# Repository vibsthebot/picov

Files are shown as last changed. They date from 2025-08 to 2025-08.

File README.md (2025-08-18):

# picov


A RP2040 powered Pico formfactor devboard using usb-c. It includes a 4x4 2020 neopixel array. The pcb was designed in KiCad.

## Schematic


## PCB


## PCB back art (designed in Figma!)


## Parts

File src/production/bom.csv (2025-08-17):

Designator | Footprint | Quantity | Value | LCSC Part #
C1, C12, C13, C14, C2, C3, C4, C5, C6 | 0402 | 9 | 100nF | C1525
C10, C7 | 0402 | 2 | 10uF | C15525
C11, C8 | 0402 | 2 | 1uF | C52923
C15, C16 | 0402 | 2 | 15pF | C1548
D1 | D_SOD-123 | 1 | 1N5819WS | C191023
J1 | USB_C_Receptacle_G-Switch_GT-USB-7010ASV | 1 | USB_C_Receptacle_USB2.0_16P | C67380
J2, J3 | PinHeader_1x20_P2.54mm_Vertical | 2 | Conn_01x20
J4 | PinHeader_1x03_P2.54mm_Vertical | 1 | Conn_01x03
J5 | SOT-23-6 | 1 | Conn_01x06 | C610271
R1, R2 | 0402 | 2 | 27 | C25100
R3, R4 | 0402 | 2 | 5k1 | C25905
R5, R7 | 0402 | 2 | 1k | C11702
R6 | 0402 | 1 | 10k | C25744
SW1, SW2 | SMD_3x4 | 2 | SW_Push | C455280
U1 | QFN-56-1EP_7x7mm_P0.4mm_EP3.2x3.2mm | 1 | RP2040 | C2040
U10, U11, U12, U13, U14, U15, U16, U17, U18, U19, U2, U5, U6, U7, U8, U9 | LED_WS2812-2020 | 16 | WS2812-2020 | C26159668
U3 | Winbond_USON-8-1EP_3x2mm_P0.5mm_EP0.2x1.6mm | 1 | W25Q16JVUXIQ_TR | C2843335
U4 | SOT-23-6 | 1 | USBLC6-2SC6 | C5180249
Y1 | Crystal_SMD_3225-4Pin_3.2x2.5mm | 1 | ABM8-272-T3 | C9002

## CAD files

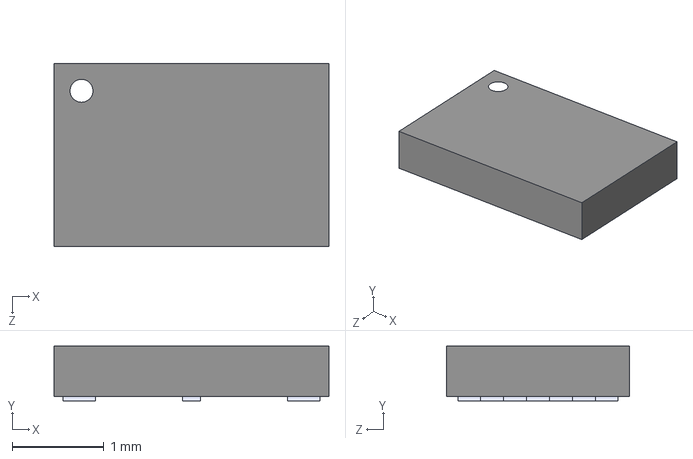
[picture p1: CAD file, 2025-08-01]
src/parts/W25Q16JVUXIQ_TR/W25Q16JVUXIQ_TR.step
3.00 x 0.6 x 2.00 mm

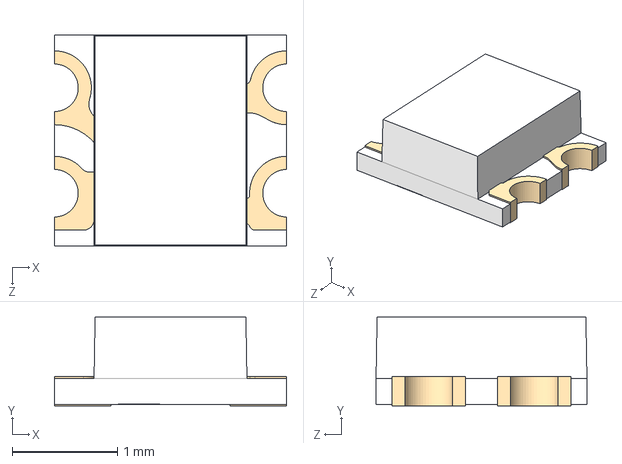
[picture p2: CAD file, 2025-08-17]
src/parts/WS2812-2020/WS2812-2020.step
2.20 x 0.84 x 2.00 mm

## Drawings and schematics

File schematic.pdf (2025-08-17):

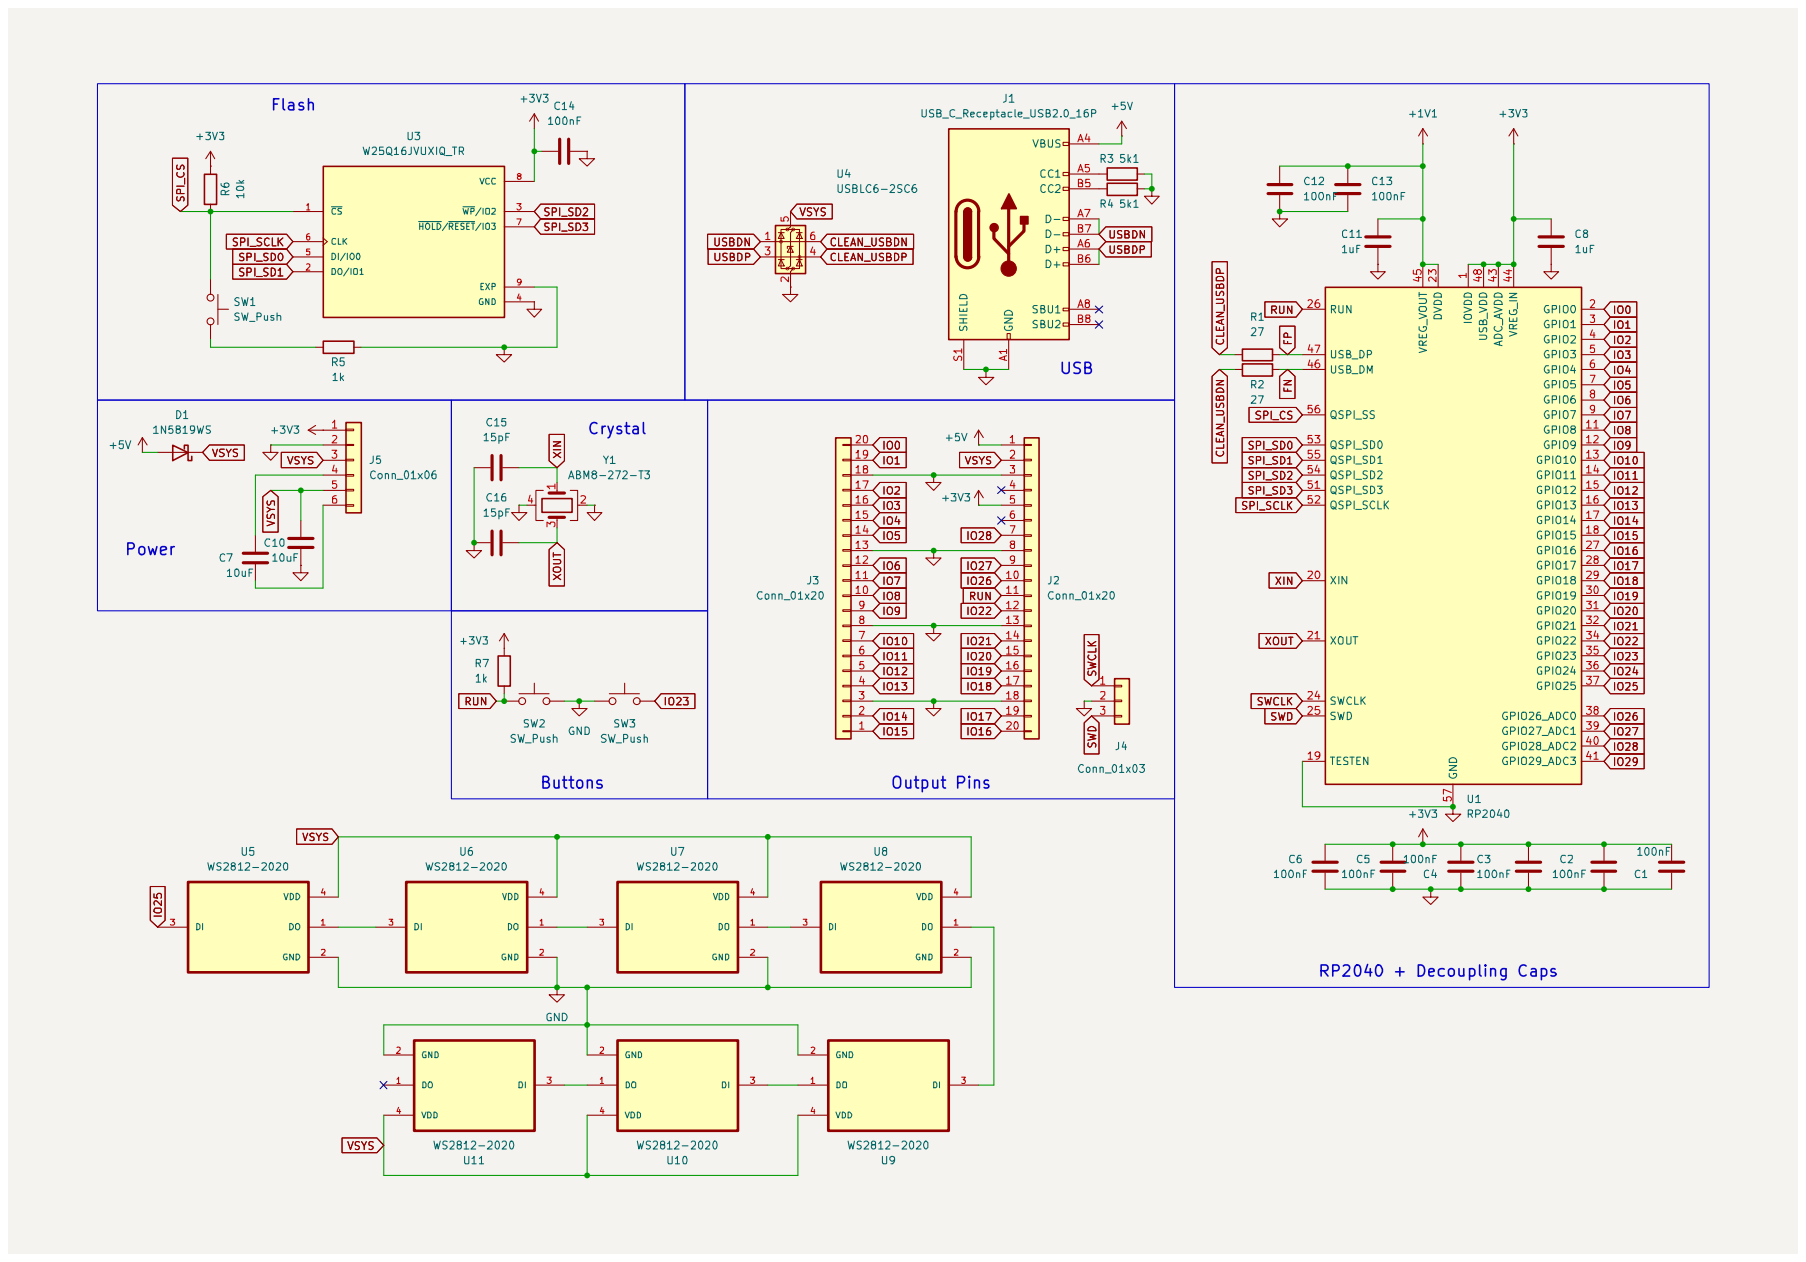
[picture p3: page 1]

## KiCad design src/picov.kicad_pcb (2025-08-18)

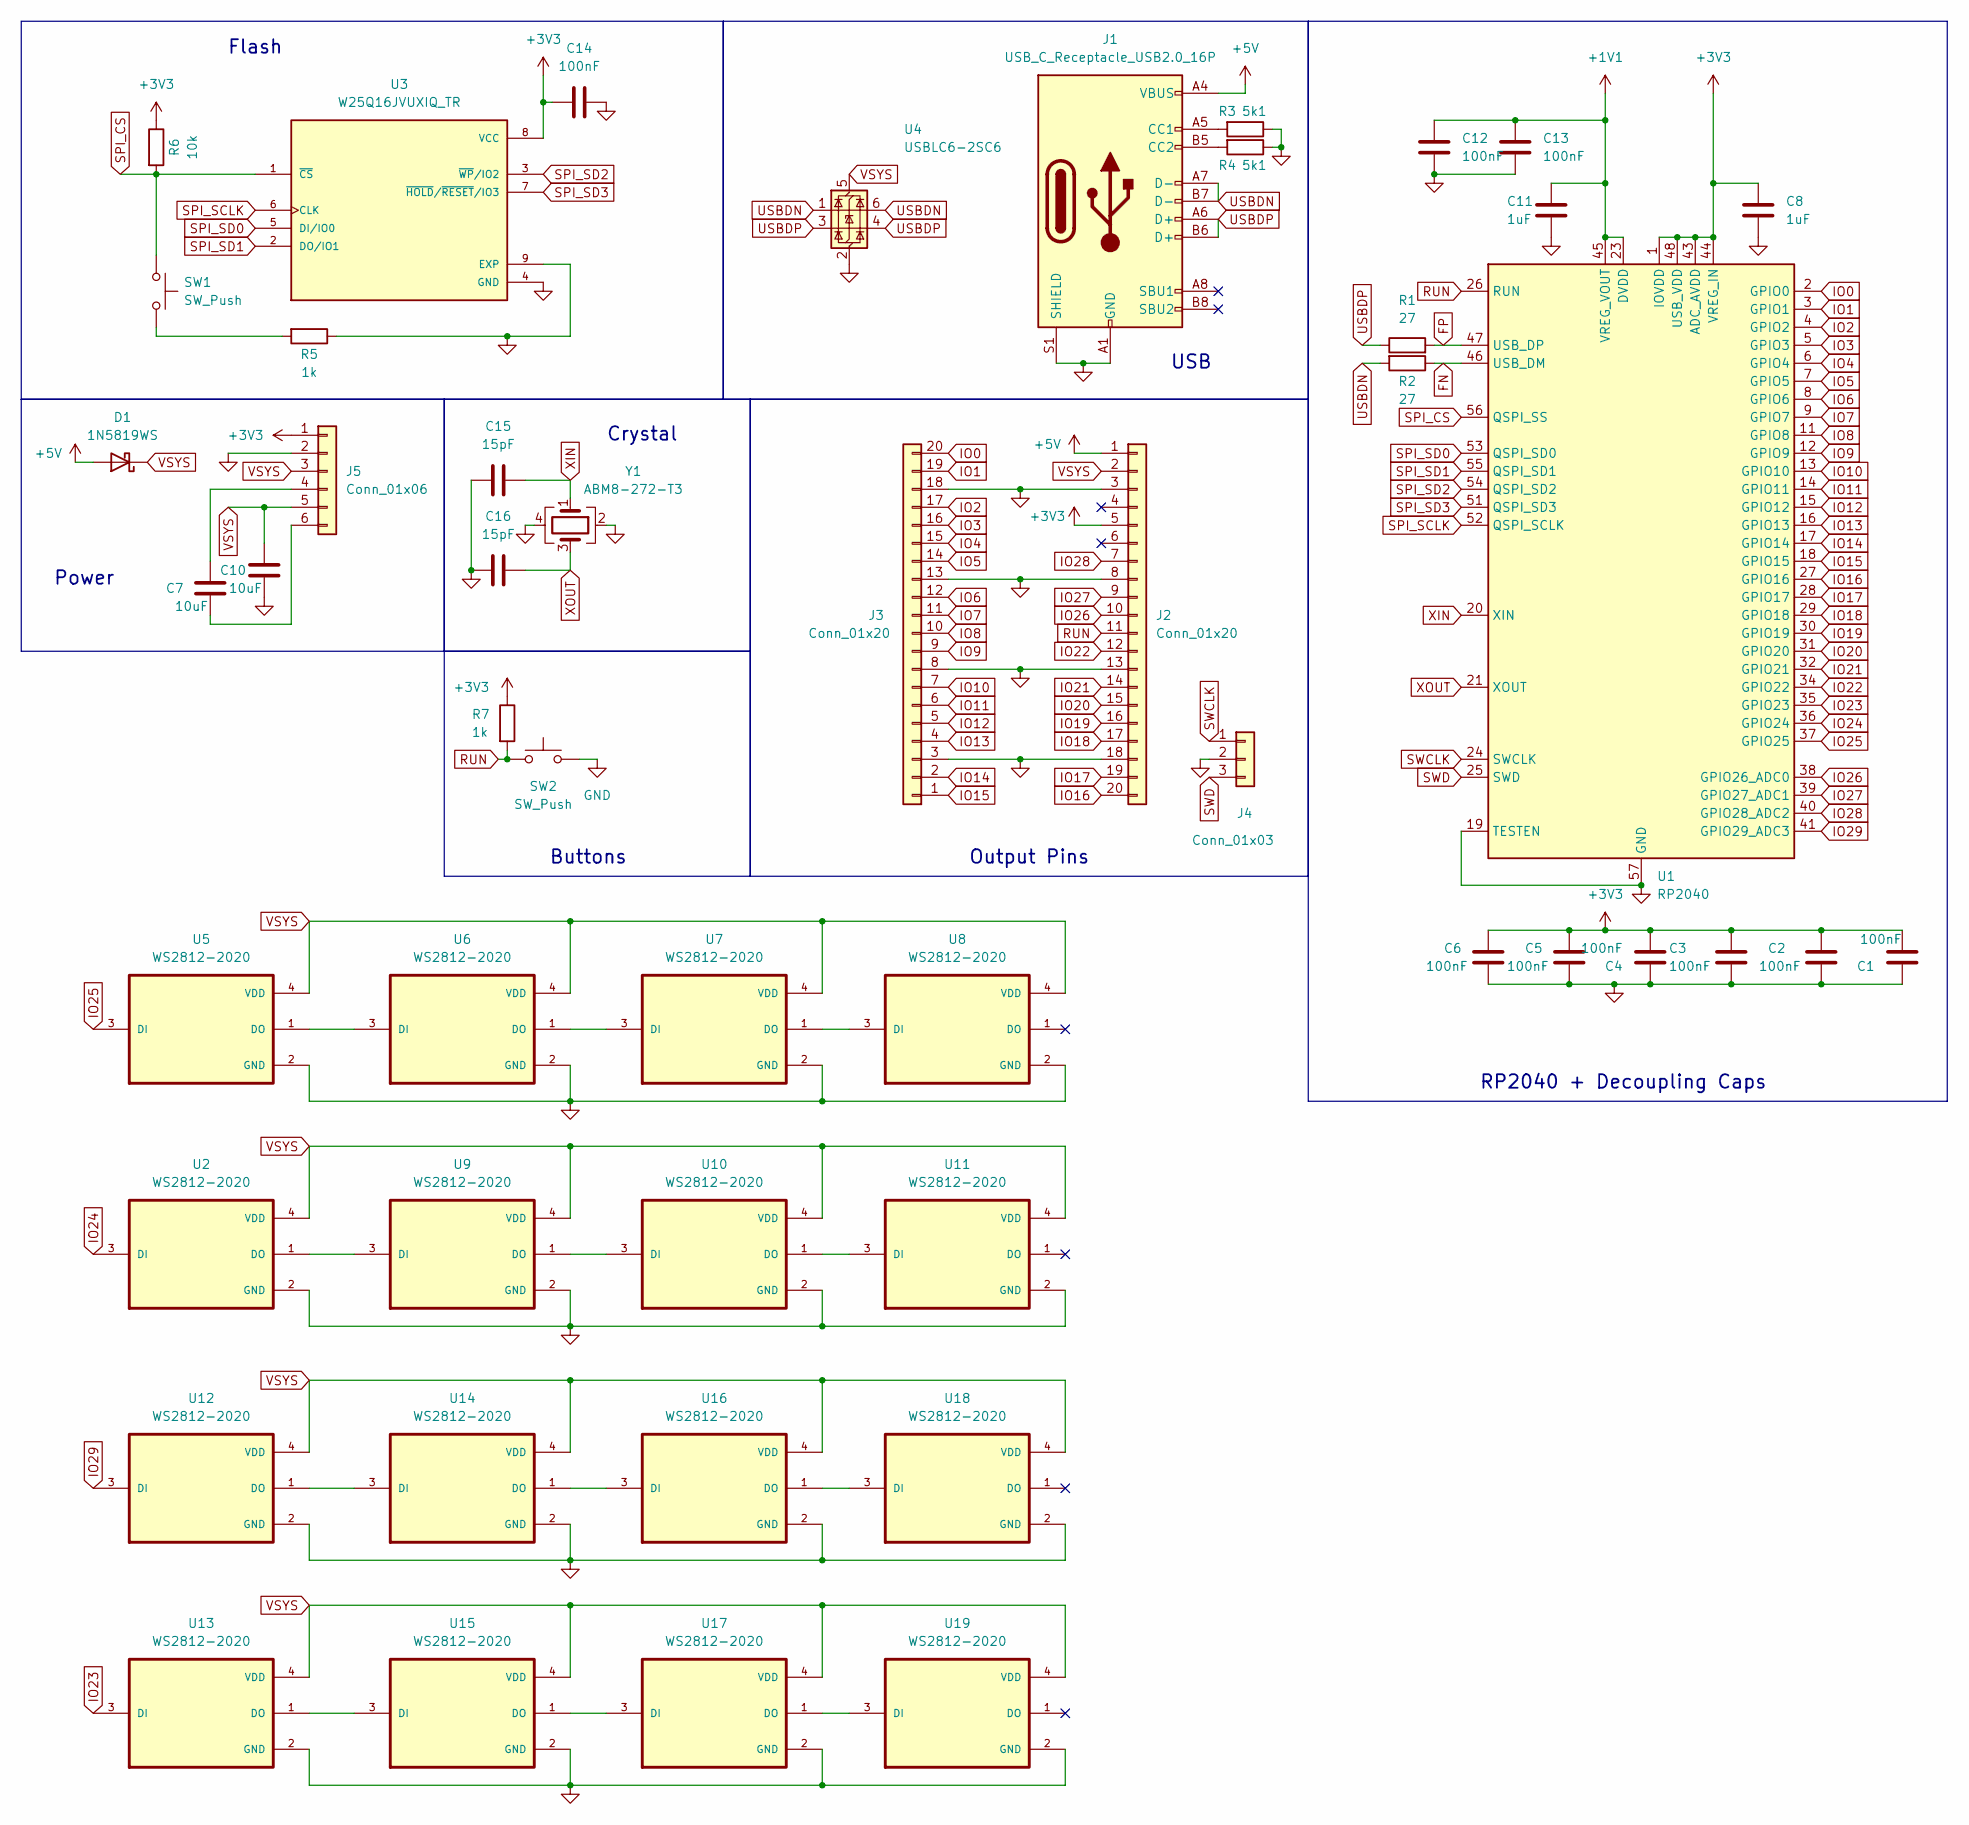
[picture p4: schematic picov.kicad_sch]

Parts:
C1, C2, C3, C4, C5, C6, C12, C13, C14: 100nF; C_0402_1005Metric; LCSC C1525
C7, C10: 10uF; C_0402_1005Metric; LCSC C15525
C8, C11: 1uF; C_0402_1005Metric; LCSC C52923
C15, C16: 15pF; C_0402_1005Metric; LCSC C1548
D1: 1N5819WS; D_SOD-123; LCSC C191023
J1: USB_C_Receptacle_USB2.0_16P; USB_C_Receptacle_G-Switch_GT-USB-7010ASV; LCSC C67380
J2, J3: Conn_01x20; PinHeader_1x20_P2.54mm_Vertical
J4: Conn_01x03; PinHeader_1x03_P2.54mm_Vertical
J5: Conn_01x06; SOT-23-6; LCSC C610271
R1, R2: 27; R_0402_1005Metric; LCSC C25100
R3, R4: 5k1; R_0402_1005Metric; LCSC C25905
R5, R7: 1k; R_0402_1005Metric; LCSC C11702
R6: 10k; R_0402_1005Metric; LCSC C25744
SW1, SW2: SW_Push; SMD_3x4; LCSC C455280
U1: RP2040; QFN-56-1EP_7x7mm_P0.4mm_EP3.2x3.2mm; LCSC C2040
U2, U5, U6, U7, U8, U9, U10, U11, U12, U13, U14, U15, U16, U17, U18, U19: WS2812-2020; LED_WS2812-2020; PARTREV V1.3; LCSC C26159668
U3: W25Q16JVUXIQ_TR; Winbond_USON-8-1EP_3x2mm_P0.5mm_EP0.2x1.6mm; PARTREV H; LCSC C2843335
U4: USBLC6-2SC6; SOT-23-6; LCSC C5180249
Y1: ABM8-272-T3; Crystal_SMD_3225-4Pin_3.2x2.5mm; LCSC C9002

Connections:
+1V1: C11.1, C12.1, C13.1, U1.23 (DVDD), U1.45 (VREG_VOUT), U1.50 (DVDD)
+3V3: C1.2, C2.2, C3.2, C4.2, C5.2, C6.2, C8.1, C14.1, J2.5, J5.1, R6.1, R7.1, U1.1 (IOVDD), U1.10 (IOVDD), U1.22 (IOVDD), U1.33 (IOVDD), U1.42 (IOVDD), U1.43 (ADC_AVDD), U1.44 (VREG_IN), U1.48 (USB_VDD), U1.49 (IOVDD), U3.8 (VCC)
+5V: D1.2 (A), J1.A4 (VBUS), J1.A9 (VBUS), J1.B4 (VBUS), J1.B9 (VBUS), J2.1
FN: R2.1, U1.46 (USB_DM)
FP: R1.2, U1.47 (USB_DP)
GND: C1.1, C2.1, C3.1, C4.1, C5.1, C6.1, C8.2, C10.2, C11.2, C12.2, C13.2, C14.2, C15.1, C16.1, J1.A1 (GND), J1.A12 (GND), J1.B1 (GND), J1.B12 (GND), J1.S1 (SHIELD), J2.3, J2.8, J2.13, J2.18, J3.3, J3.8, J3.13, J3.18, J4.2, J5.2, R3.1, R4.1, R5.1, SW2.2, U1.19 (TESTEN), U1.57 (GND), U2.2 (GND), U3.4 (GND), U3.9 (EXP), U4.2 (GND), U5.2 (GND), U6.2 (GND), U7.2 (GND), U8.2 (GND), U9.2 (GND), U10.2 (GND), U11.2 (GND), U12.2 (GND), U13.2 (GND), U14.2 (GND), U15.2 (GND), U16.2 (GND), U17.2 (GND), U18.2 (GND), U19.2 (GND), Y1.2, Y1.4
IO0: J3.20, U1.2 (GPIO0)
IO1: J3.19, U1.3 (GPIO1)
IO2: J3.17, U1.4 (GPIO2)
IO3: J3.16, U1.5 (GPIO3)
IO4: J3.15, U1.6 (GPIO4)
IO5: J3.14, U1.7 (GPIO5)
IO6: J3.12, U1.8 (GPIO6)
IO7: J3.11, U1.9 (GPIO7)
IO8: J3.10, U1.11 (GPIO8)
IO9: J3.9, U1.12 (GPIO9)
IO10: J3.7, U1.13 (GPIO10)
IO11: J3.6, U1.14 (GPIO11)
IO12: J3.5, U1.15 (GPIO12)
IO13: J3.4, U1.16 (GPIO13)
IO14: J3.2, U1.17 (GPIO14)
IO15: J3.1, U1.18 (GPIO15)
IO16: J2.20, U1.27 (GPIO16)
IO17: J2.19, U1.28 (GPIO17)
IO18: J2.17, U1.29 (GPIO18)
IO19: J2.16, U1.30 (GPIO19)
IO20: J2.15, U1.31 (GPIO20)
IO21: J2.14, U1.32 (GPIO21)
IO22: J2.12, U1.34 (GPIO22)
IO23: U1.35 (GPIO23), U13.3 (DI)
IO24: U1.36 (GPIO24), U2.3 (DI)
IO25: U1.37 (GPIO25), U5.3 (DI)
IO26: J2.10, U1.38 (GPIO26_ADC0)
IO27: J2.9, U1.39 (GPIO27_ADC1)
IO28: J2.7, U1.40 (GPIO28_ADC2)
IO29: U1.41 (GPIO29_ADC3), U12.3 (DI)
unnamed: J1.A5 (CC1), R3.2
unnamed: J1.B5 (CC2), R4.2
unnamed: C7.1, J5.4
unnamed: C7.2, J5.6
unnamed: R5.2, SW1.2
unnamed: U2.1 (DO), U9.3 (DI)
unnamed: U5.1 (DO), U6.3 (DI)
unnamed: U6.1 (DO), U7.3 (DI)
unnamed: U7.1 (DO), U8.3 (DI)
unnamed: U9.1 (DO), U10.3 (DI)
unnamed: U10.1 (DO), U11.3 (DI)
unnamed: U12.1 (DO), U14.3 (DI)
unnamed: U13.1 (DO), U15.3 (DI)
unnamed: U14.1 (DO), U16.3 (DI)
unnamed: U15.1 (DO), U17.3 (DI)
unnamed: U16.1 (DO), U18.3 (DI)
unnamed: U17.1 (DO), U19.3 (DI)
RUN: J2.11, R7.2, SW2.1, U1.26 (RUN)
SPI_CS: R6.2, SW1.1, U1.56 (QSPI_SS), U3.1 (~CS)
SPI_SCLK: U1.52 (QSPI_SCLK), U3.6 (CLK)
SPI_SD0: U1.53 (QSPI_SD0), U3.5 (DI/IO0)
SPI_SD1: U1.55 (QSPI_SD1), U3.2 (DO/IO1)
SPI_SD2: U1.54 (QSPI_SD2), U3.3 (~WP/IO2)
SPI_SD3: U1.51 (QSPI_SD3), U3.7 (~HOLD/~RESET/IO3)
SWCLK: J4.1, U1.24 (SWCLK)
SWD: J4.3, U1.25 (SWD)
USBDN: J1.A7 (D-), J1.B7 (D-), R2.2, U4.1 (I/O1), U4.6 (I/O1)
USBDP: J1.A6 (D+), J1.B6 (D+), R1.1, U4.3 (I/O2), U4.4 (I/O2)
VSYS: C10.1, D1.1 (K), J2.2, J5.3, J5.5, U2.4 (VDD), U4.5 (VBUS), U5.4 (VDD), U6.4 (VDD), U7.4 (VDD), U8.4 (VDD), U9.4 (VDD), U10.4 (VDD), U11.4 (VDD), U12.4 (VDD), U13.4 (VDD), U14.4 (VDD), U15.4 (VDD), U16.4 (VDD), U17.4 (VDD), U18.4 (VDD), U19.4 (VDD)
XIN: C15.2, U1.20 (XIN), Y1.1
XOUT: C16.2, U1.21 (XOUT), Y1.3

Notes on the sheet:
Buttons
Output Pins
Flash
Power
USB
RP2040 + Decoupling Caps
Crystal

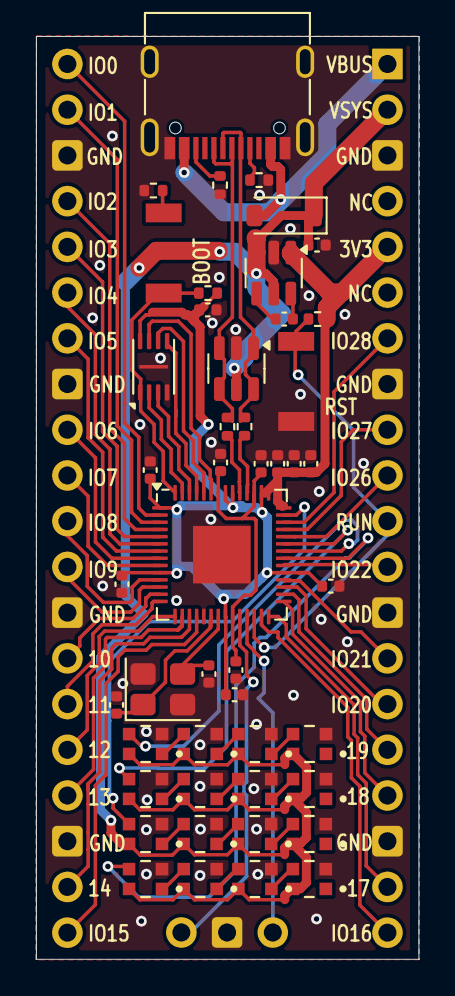
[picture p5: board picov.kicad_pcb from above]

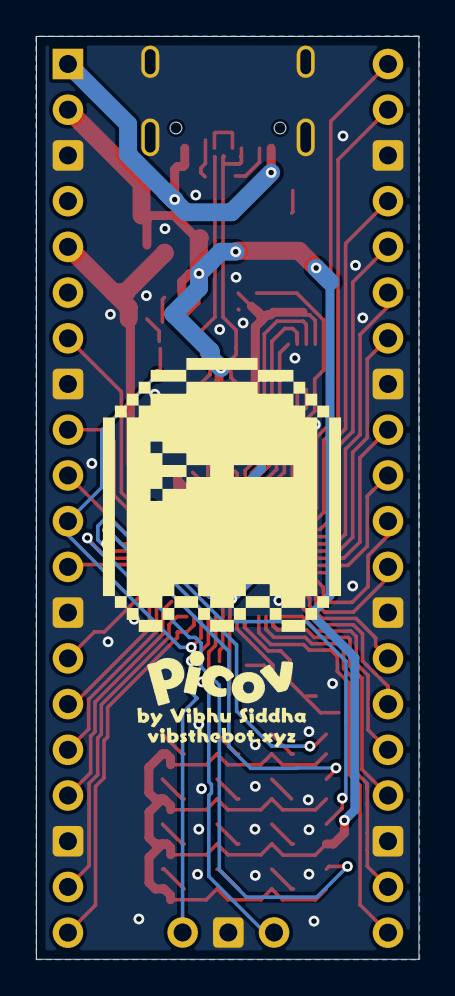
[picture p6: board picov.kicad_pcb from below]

Board: 2 copper layers, 21.2 x 51.3 mm, 50 parts (3 on the bottom side), 67 nets.

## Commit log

2025-08-01 Got basic schematic done, need to add flash
    [W25Q16JVUXIQ_TR.step, picov.kicad_pcb, picov.kicad_sch]
2025-08-03 added castellated holes for sides, basic layout done
    [picov.kicad_pcb, picov.kicad_sch]
2025-08-10 Finished all design for the pcb
    [bom.csv, designators.csv, picov.kicad_pcb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]
2025-08-17 finished pcb!
    [W25Q16JVUXIQ_TR.step, WS2812-2020.step, bom.csv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]
2025-08-17 cleaned up production files, finished readme
    [bom.csv, designators.csv, picov.kicad_pcb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]
2025-08-17 removed castellated holes due to high jlcpcb pricing, finished 4x4 neopixel matrix
    [bom.csv, designators.csv, picov.kicad_pcb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]
2025-08-18 changed some routing
    [picov.kicad_pcb, picov.kicad_sch]
